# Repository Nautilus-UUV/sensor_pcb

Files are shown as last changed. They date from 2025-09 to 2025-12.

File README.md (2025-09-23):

# sensor_pcb
## External sensors
Those sensors just go over I2C. A connector needs to be placed on the PCB. The Leak sensor will just expose the probes.

* Temperature: https://bluerobotics.com/store/sensors-cameras/sensors/celsius-sensor-r1/
* Pressure: https://bluerobotics.com/store/sensors-cameras/sensors/bar-depth-pressure-sensor/
* Leak sensor: https://bluerobotics.com/store/sensors-cameras/leak-sensor/sos-leak-sensor/

## Internal sensors
Those are also connected to the I2C bus but are on the pcb thus internal. 

* Temperature + Humidity: SHT45-AD1B Datasheet
* Pressure Sensor: BMP581 Product Page
* Tank Pressure: ADS1115  Datesheet Note: The tank pressure is an analog signal. Plase design and layout the pcb so that a optional resistor devider could be used but normaly is not used

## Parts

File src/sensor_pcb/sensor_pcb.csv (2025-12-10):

Qty | IPN | MPN | Manufacturer | SPN
11 | C-100n-0603 | 885012206095 | Wurth Elektronik | 710-885012206095
1 | C-10n-0603 | 885012206089 | Wurth Elektronik | 710-885012206089
1 | C-1u-0603 | 885012206126 | Wurth Elektronik | 710-885012206126
1 | C-4.7n-0603 | 885012206087 | Wurth Elektronik | 710-885012206087
2 | C-10p-0603 | 885012006051 | Wurth Elektronik | 710-885012006051
1 | D-WUR-150060RS73220 | 150060RS73220 | Würth Elektronik | 710-150060RS73220
8 | D-WUR-150060BS73220 | 150060BS73220 | Würth Elektronik | 710-150060BS73220
7 | D-TVS-SMBJ3V3 | SMBJ3V3-M3/52 | Vishay General Semiconductor | 78-SMBJ3V3-M3/52
6 | WURT-710-82402374 | 710-82402374 | Wurth Elektronik | 710-82402374
1 | L-MUR-BLM18SP101SN1 | BLM18SP101SN1 | Murata | 81-BLM18SP101SN1D
1 | COMM-TI-TCAN3414DRBR | TCAN3414DRBR | Texas Instruments | 595-TCAN3414DRBR
2 | CON-WUR-66200421024 | 66200421024 | Würth Elektronik | 66200421024
2 | CON-WUR-643280100305 | 643280100305 | Würth Elektronik | 710-643280100308
2 | CON-WUR-66200821024 | 66200821024 | Würth Elektronik | 66200821024
1 | CON-SAMTEC-FTSH-107-02-L-DV | FTSH-107-02-L-DV | Samtec | 200-FTSH10702LDV
1 | D-WURT-710-150060RS83000 | 710-150060RS83000 | Wurth Elektronik | 710-150060RS83000
8 | Q-NPN-200-SOT23 | MMBT3904-7-F | Diodes Incorporated | 621-MMBT3904-F
3 | R-10k-0603 | 560112116005 | Wurth Elektronik | 710-560112116005
2 | R-100-0603 | 560112116009 | Wurth Elektronik | 710-560112116009
25 | R-1k-0603 | 560112116014 | Wurth Elektronik | 710-560112116014
8 | R-27k-0603 | 560112116023 | Wurth Elektronik | 710-560112116023
2 | R-100k-0603 | 560112116004 | Wurth Elektronik | 710-560112116004
1 | R-0-0603 | RCA06030000ZSTA | Vishay | 71-RCA06030000ZSTA
1 | M-OMR-B3F1052 | B3F-1052 | Omron | 653-B3F-1052
6 | M-TEST-SMT_1.5mm_round
1 | D-SENS-SHT40-AD1F-R2 | SHT40-AD1F-R2 | Sensirion | 403-SHT40-AD1F-R2
1 | IC-ADC-ADS1115-MSOP | ADS1115IDGS | Texas Instruments | 595-ADS1115IDGSR
1 | M-STM-STM32L451CET6 | STM32L451CET6 | STMicroelectronics | 511-STM32L451CET6
1 | D-BOSCH-BMP581 | BMP581 | Bosch Sensortec | 262-BMP581
1 | Y-WUERTH-830064296 | 830064296 | Würth Elektronik | 710-830064296
2 | D-TSV-824094024 | 824094024 | Würth Elektronik | 710-824094024

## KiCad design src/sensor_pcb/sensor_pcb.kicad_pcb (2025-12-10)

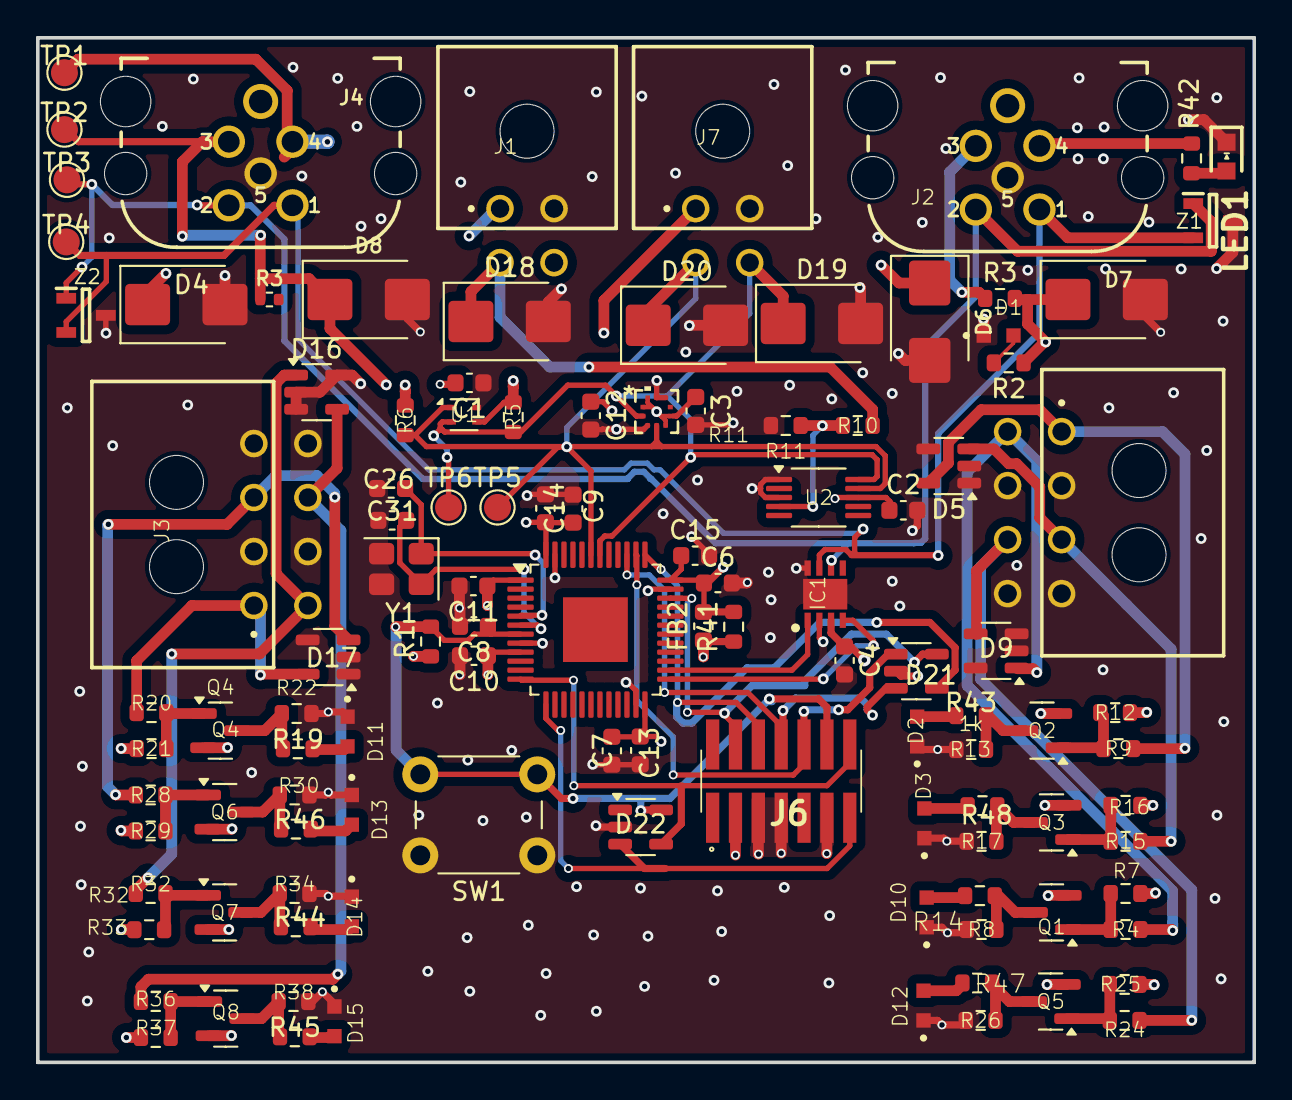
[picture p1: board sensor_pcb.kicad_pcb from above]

Board: 4 copper layers, 67.6 x 56.9 mm, 112 parts (0 on the bottom side), 55 nets.

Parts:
C1, C2, C3, C4, C6, C8, C10, C11, C12, C13, C14: 100nF; C_0603_1608Metric
C7: 10nF; C_0603_1608Metric
C9: 1uF; C_0603_1608Metric
C15: 4.7nF; C_0603_1608Metric
C26, C31: 10pF; C_0603_1608Metric
D1: 150060RS73220; LED_0603
D2, D3, D10, D11, D12, D13, D14, D15: 150060BS73220; LED_0603
D4, D6, D7, D8, D18, D19, D20: SMBJ3.3A; D_SMB
D5, D9, D16, D17, D21, D22: 710-82402374; SOT-23-5
FB2: 100Ω@100MHz; L_0603_1608Metric
IC1: TCAN3414DRBR
J1, J7: 66200421024; Wurth_66200421024
J2, J4: 643280100305; Wuerth_WR_CIRCM_643280100305
J3, J5: 66200821024; Wurth_66200821024
J6: FTSH-107-02-L-DV; FTSH-107-XX-YYY-DV
LED1: 710-150060RS83000; Wuerth_LED_150060RS83000
Q1, Q2, Q3, Q4, Q5, Q6, Q7, Q8: NPN BJT 40V 200mA; SOT-23
R1, R5, R6: 10k; R_0603_1608Metric
R2, R3#2: 100; R_0603_1608Metric
R3: 100; R_0402_1005Metric
R4, R8, R9, R13, R14, R15, R17, R19, R20, R22, R24, R26, R28, R30, R32, R34, R36, R38, R42, R43, R44, R45, R46, R47, R48: 1k; R_0603_1608Metric
R7, R12, R16, R21, R25, R29, R33, R37: 27k; R_0603_1608Metric
R10, R11: 100k; R_0603_1608Metric
R41: 0; R_0603_1608Metric
SW1: Button Switch SPST-No; SW_PUSH_6mm
TP1, TP2, TP3, TP4, TP5, TP6: Test Point; TestPoint_Pad_D1.5mm
U1: SHT45-AD1B; Sensirion_DFN-4_1.5x1.5mm_P0.8mm_SHT4x_NoCentralPad
U2: 16-bit ADC; VSSOP-10_3x3mm_P0.5mm
U3: STM32L451CET6
U4: BMP581; QFN10_BMP581_BOS
Y1: 16.0MHz; Crystal_SMD_3225-4Pin_3.2x2.5mm
Z1, Z2: 824094024; SOT95P240X104-3N

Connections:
+3.3V: C1.2, C2.1, C3.1, C4.1, C6.1, C7.1, C9.1, C10.1, C11.1, C12.1, C13.1, C14.1, C15.1, D7.1 (K), D8.1 (K), FB2.1, FB2.2, IC1.3 (V_CC), J4.3, J6.3, J7.1, Q1.2 (E), Q2.2 (E), Q3.2 (E), Q4.2 (E), Q5.2 (E), Q6.2 (E), Q7.2 (E), Q8.2 (E), R1.1, R2.1, R3.1, R3#2.2, R5.2, R6.2, R7.1, R12.1, R16.1, R21.1, R25.1, R29.1, R33.1, R37.1, R41.1, R41.2, TP2.1, U1.3 (VDD), U2.8 (VDD), U3.1 (VBAT), U3.9 (VDDA), U3.24 (VDD), U3.36 (VDD), U3.48 (VDD), U4.1 (VDDIO), U4.5 (SDO), U4.6 (CSB), U4.10 (VDD)
+5V: D4.1 (K), D6.1 (K), J1.1, J2.4, J4.4, R42.1, TP1.1
/CAN_H: IC1.7 (CANH), J2.1, J4.1, TP4.1, Z1.2 (I/O_2), Z2.2 (I/O_2)
/CAN_L: IC1.6 (CANL), J2.2, J4.2, TP3.1, Z1.1 (I/O_1), Z2.1 (I/O_1)
/ls 1.1: D5.5 (K), J5.1, R9.1
/ls 2.1: D5.3 (K), J5.3, R15.1
/ls 3.1: D9.1 (K), J5.5, R4.1
/ls 4.1: D9.4 (K), J5.7, R24.1
/ls 5.1: D17.5 (K), J3.1, R20.1
/ls 6.1: D17.3 (K), J3.3, R28.1
/ls 7.1: D16.1 (K), J3.5, R32.1
/ls 8.1: D16.4 (K), J3.7, R36.1
/p_out: D18.1 (K), J1.3, R10.1
/s 1.1: Q2.3 (C), R13.1, R43.1
/s 2.1: Q3.3 (C), R17.1, R48.1
/s 3.1: Q1.3 (C), R8.1, R14.1
/s 4.1: Q5.3 (C), R26.1, R47.1
/s 5.1: Q4.3 (C), R19.1, R22.1
/s 6.1: Q6.3 (C), R30.1, R46.1
/s 7.1: Q7.3 (C), R34.1, R44.1
/s 8.1: Q8.3 (C), R38.1, R45.1
/sensor_stm/CAN.RX: IC1.4 (RXD), U3.25 (PB12)
/sensor_stm/CAN.TX: IC1.1 (TXD), U3.26 (PB13)
/sensor_stm/JTAG_TCK/SWCLK: D21.4 (K), J6.6, U3.37 (PA14)
/sensor_stm/JTAG_TDI: D21.1 (K), J6.10, U3.38 (PA15)
/sensor_stm/JTAG_TDO/SWD: D21.3 (K), J6.8, U3.39 (PB3)
/sensor_stm/JTAG_TMS/SWDIO: D21.5 (K), J6.4, U3.34 (PA13)
/sensor_stm/OSC_IN: C26.1, U3.5 (PH0), Y1.1
/sensor_stm/OSC_OUT: C31.1, U3.6 (PH1), Y1.4
/sensor_stm/SCL: D19.1 (K), J7.4, R5.1, TP6.1, U1.2 (SCL), U2.10 (SCL), U3.42 (PB6), U4.2 (SCK)
/sensor_stm/SDA: D20.1 (K), J7.3, R6.1, TP5.1, U1.1 (SDA), U2.9 (SDA), U3.43 (PB7), U4.4 (SDI)
/sensor_stm/UART0.RX: D22.3 (K), J6.13, U3.13 (PA3)
/sensor_stm/UART0.TX: D22.4 (K), J6.14, U3.12 (PA2)
/sensor_stm/nRST: C8.1, D22.5 (K), J6.12, R1.2, SW1.2, U3.7 (NRST)
GND: C1.1, C2.2, C3.2, C4.2, C6.2, C7.2, C8.2, C9.2, C10.2, C11.2, C12.2, C13.2, C14.2, C15.2, C26.2, C31.2, D1.C, D2.C, D3.C, D4.2 (A), D5.1 (K), D5.2 (A), D5.4 (K), D6.2 (A), D7.2 (A), D8.2 (A), D9.2 (A), D9.3 (K), D9.5 (K), D10.C, D11.C, D12.C, D13.C, D14.C, D15.C, D16.2 (A), D16.3 (K), D16.5 (K), D17.1 (K), D17.2 (A), D17.4 (K), D18.2 (A), D19.2 (A), D20.2 (A), D21.2 (A), D22.2 (A), IC1.2 (GND), IC1.8 (STB), IC1.9 (EP), J1.2, J2.5, J3.2, J3.4, J3.6, J3.8, J4.5, J5.2, J5.4, J5.6, J5.8, J6.5, J6.7, J6.11, J7.2, LED1.1 (K), R8.2, R11.2, R13.2, R17.2, R22.2, R26.2, R30.2, R34.2, R38.2, SW1.1, U1.4 (VSS), U2.1 (ADDR), U2.3 (GND), U3.8 (VSSA), U3.23 (VSS), U3.35 (VSS), U3.47 (VSS), U4.3 (VSS_1), U4.8 (VSS_2), U4.9 (VSS_3), Y1.2, Y1.3, Z1.3 (GND), Z2.3 (GND)
unnamed: D1.A, R2.2
unnamed: D2.A, R43.2
unnamed: D3.A, R48.2
unnamed: D10.A, R14.2
unnamed: D11.A, R19.2
unnamed: D12.A, R47.2
unnamed: D13.A, R46.2
unnamed: D14.A, R44.2
unnamed: D15.A, R45.2
unnamed: J2.3, R3#2.1
unnamed: LED1.2 (A), R42.2
unnamed: Q1.1 (B), R4.2, R7.2
unnamed: Q2.1 (B), R9.2, R12.2
unnamed: Q3.1 (B), R15.2, R16.2
unnamed: Q4.1 (B), R20.2, R21.2
unnamed: Q5.1 (B), R24.2, R25.2
unnamed: Q6.1 (B), R28.2, R29.2
unnamed: Q7.1 (B), R32.2, R33.2
unnamed: Q8.1 (B), R36.2, R37.2
unnamed: R10.2, R11.1, U2.4 (AIN0)

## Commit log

2025-10-07 added water and temp sensor
    [sensor_pcb.kicad_pcb, sensor_pcb.kicad_sch]
2025-10-07 adc added
2025-10-14 pressure sensor added
    [sensor_pcb.kicad_sch, untitled.kicad_sch]
2025-10-18 small fixes
    [leak_sensors.kicad_sch, sensor_pcb.kicad_sch, untitled.kicad_sch]
2025-10-18 added connectors
    [leak_sensors.kicad_sch, stm.kicad_sch]
2025-10-21 8 pin connectors added
    [leak_sensors.kicad_sch, sensor_pcb.kicad_pcb, sensor_pcb.kicad_sch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]
2025-10-21 v1 complete
    [leak_sensors.kicad_sch, sensor_pcb.kicad_sch, stm.kicad_sch]
2025-11-04 schematic update
    [leak_sensors.kicad_sch, stm.kicad_sch]
2025-11-18 intermediate changes
    [leak_sensors.kicad_sch, sensor_pcb.kicad_pcb, sensor_pcb.kicad_sch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]
2025-11-18 tuesday changes
    [leak_sensors.kicad_sch]
2025-11-20 fixing up parts according to kicad auto errors
    [sensor_pcb.kicad_pcb, sensor_pcb.kicad_sch]
2025-11-20 removed error messages
    [sensor_pcb.kicad_pcb, sensor_pcb.kicad_sch, stm.kicad_sch]
2025-12-02 finalizing pcb
2025-12-02 Sensor PCB suggestion Davide
    [sensor_pcb.kicad_pcb, sensor_pcb.kicad_sch]
2025-12-02 added stm
    [sensor_pcb.kicad_sch, sensor_stm.kicad_sch]
2025-12-02 pcb updates to stm
2025-12-02 clearing up errors
    [sensor_pcb.kicad_pcb]
2025-12-03 final changes before review
    [sensor_pcb.kicad_pcb, sensor_pcb.kicad_sch, sensor_stm.kicad_sch]
2025-12-03 making schematic prettier
    [sensor_stm.kicad_sch]
2025-12-09 quick changes to gnd
2025-12-09 quick save on progress
    [sensor_pcb.kicad_pcb]
2025-12-09 bom process
    [leak_sensors.kicad_sch, sensor_pcb.csv, sensor_pcb.kicad_sch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]
2025-12-10 changes from wrong db
    [leak_sensors.kicad_sch, sensor_pcb.csv, sensor_pcb.kicad_pcb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]
2025-12-10 changed to bigger footprints on resistors
    [sensor_pcb.csv, sensor_stm.kicad_sch]
2025-12-10 symbol update for spn
    [sensor_pcb.kicad_pcb]
